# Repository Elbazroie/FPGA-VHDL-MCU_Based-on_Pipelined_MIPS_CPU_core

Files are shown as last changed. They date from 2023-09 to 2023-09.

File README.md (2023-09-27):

# FPGA-VHDL-MCU_Based-on_Pipelined_MIPS_CPU_core

This VHDL design includes Microcontroller UNIT based on MIPS PIPELINE CPU with one Delay slot architecture.

  The MCU design includes modules such as GPIO (LEDR,HEX0-5,SWITCH,KEYS), Basic Timer with OUTMOD capabilities and
	Interrupt controller Module with up to 5 PRIORITY interrupts (KEYS0-3, BASIC TIMER, NMI).

  The MIPS PIPLLINE design also includes HAZARD and forwarding unit that support stall and flush, to deal with RAW and control hazards (branch), and 
	added HARDWARE exclusively for INTERRUPT capabilities.
	the entire ISA supported included in the control.vhd file.

The design has been compiled and loaded to the FPGA Altera board ( Cyclone V ) for testing

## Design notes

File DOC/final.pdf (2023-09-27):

רועי אלבז 205868011
דור פטשניק 205556533

# Final Project

## MCU: based on Pipeline MIPS CPU - FPGA

בדו"ח זה נציג את הניתוח מימוש המיקרו בקר שתכננו המבוסס על מעבד מסוג MIPS pipelined

## Table of Contents

4 | ModelSim
8 | Quartus
18 | Signal Tap
מסקנות 20 |

אופן פעולה

בחלק זה נסביר את אופן הפעולה של הדיזיין שלנו MCU, ונכלול גם את התוספות והשינוים אותם

נדרשנו לבצע על מנת לתמוך במעבד מבוסס Pipeline MIPS.

דיאגרמת בלוקים כללית של הרכיב:

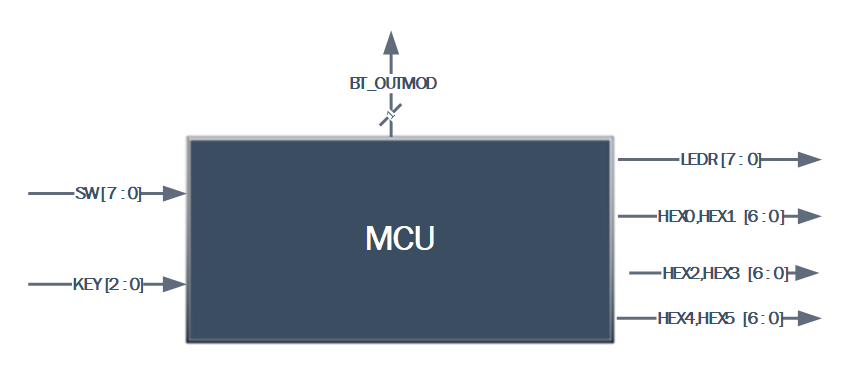
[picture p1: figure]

המיקרו-בקר שלנו מורכב מהרכיבים הבאים:

MIPS Pipeline | מבוסס | MIPS | מעבד | •
- מרכיבי GPIO בעלי יכולת קריאה וכתיבה )קריאה בלבד במקרה של רכיב INPUT )
- TIMER BASIC- בעל יכולת פסיקה בעת OVERFLOW ויציאת אות PWM בעל DUTY

CYCLE משתנה.

- CONTROLLER INTERRUPT- בעל יכולת פסיקה עם יכולת PRIORITY של פסיקה

ניתנות למיסוך ו-NMI. תומך בפסיקה מלחצנים, מTIMER ובביצוע RESET.

רכיבי GPIO:

מימשנו רכיבים אלה בצורה דומה להגדרת המשימה בתיאור הפרויקט. רכיבים אלה תלוים במודול

Select Chip אשר מעביר את קו הבקרה המתאים בהתאם לקידוד של קווי הכתובת הרלוונטים.

רגיסטרים בעלי יכולת כתיבה וקריאה )כגון IFG, BTCNT וכו'( מימשנו עם תוספת של בורר בכניסה

לרגיסטר שנפתח רק כאשר מתבצעת כתיבה או קריאה מהרכיב ועוצר את פעולתו, על מנת למנוע

מצב של DRIVEN MULTIPLE.

:INTERRUPT CONTROLLER

תוכנן כפי שהוגדר בהגדרת המשימה, עם תמיכה בפסיקות עם PRIORITY. מעלה קו בקרה INTR

בתחילת פסיקה ומקבל קו בקרה INTA בתחילת פעולת הפסיקה ומסיים את פעולתו כאשר קו זה

חוזר לערך 1 לוגי. כמו כן הוא מחובר באופן בלעדי לכפתור הRESET ומבצע אותו בתור פסיקה.

שאר המודולים במערכת מקבלים את הRESET ממודול זה על ידי קו בקרה סינכרוני NMI. כמו כן,

בעת RESET אנו מאפסים גם את מוצאי רכיבי הGPIO על ידי ערך הTYPE הנמצא על גבי

הDATABUS( ערכו הוא 0 בעת RESET)

:MIPS Pipeline

מעבד הPIPELINE ממעבדה 5 בעל מספר תוספות לתמיכה בפסיקות וGPIO:

.1 GPIO – עבודה אך ורק בשלב הDMEMORY.

a. תוספת של 2 TRISTATES בחיבור לdataBUS: במוצא הזכרון ובכניסת המידע

לזכרון. )עבור כתיבה וקריאה(

b. מניעת כתיבה לזכרון בעת פניה לרכיבי IO.
c. חיבור קו הכתובת בכניסה לזכרון אל הaddressBUS.

– INTERRUPT CONTROLLER .2

a. תוספת של MUX לקו הכתובת בכניסה לזכרון על מנת לכתוב את הTYPE בביצוע

.INTERRUPT

b. תוספת של קו EPC המחזיק את הכתובת הנכונה לקפיצה בשלב הEXECUTE.

נדרשנו להוסיף לוגיקה לתמיכה בjump conditional אשר משנה את הערך הבא

לקפיצה עקב שינוי הערך של הPC.

c. תמיכה בקפיצה לכתובת הפסיקה על ידי 2 ביטי עזר ISR המבצעים אמולציה של

פקודות LW וJAL.

d. העלאה והורדה של ביט הGIE בתחילת רוטינת פסיקה ובקבלת פקודת RETI.
e. הוספת STALL ליחידת ה HAZARD בעת ביצוע כתיבה לIFG לפני חזרה מרוטינת

פסיקה ) מונע מצב של כניסה לפסיקה נוספת למרות שהדגל המתאים היה אמור

לרדת(

ModelSim

נבצע את הניתוח בתוכנת ModelSim עבור מספר תוכניות שונות, ונבחן את התוצאות.

להלן קומפילציה של הדיזיין שלנו בתוכנת modelsim:

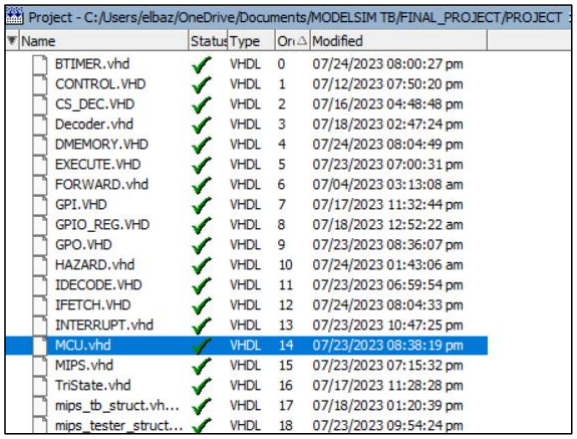
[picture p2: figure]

בשלב הסימולציה במודל סים נציג 5 טסטים לדוגמא: 2 עבור תקינות הGPIO, 2 עבור ה interrupt

controller ועוד בדיקה עבור אות הPWM של השעון.

:GPIO

קוד לדוגמא - 0Test:

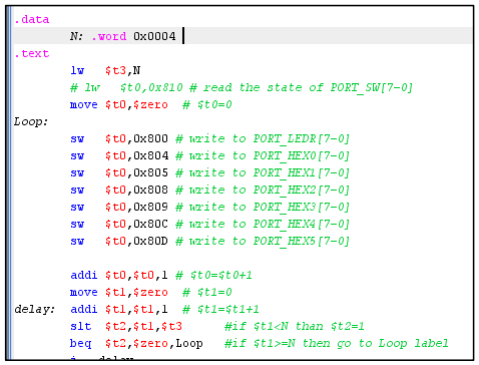
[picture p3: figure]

איור :2 קוד אסמבלי לדוגמא – 0test

איור :1 קומפילציה בMODELSIM עבור הMCU

בקוד זה אנו בודקים את תקינות רכיבי הGPO: HEX,LEDR. מבצעים מניה מעלה החל מהערך 0 וטוענים אותו ללדים ולנורות הHEX, עם דיליי של N.

בתמונה זו ניתן לראות את אופן הפעולה התקין – מניה מעלה של רכיבי הGPO שלנו. נציין כי ערכי

הHEX הן לאחר DECODE על מנת שיתאים לתצוגה על גבי הFPGA ולכן הם שונים מהערכים על

הלדים:

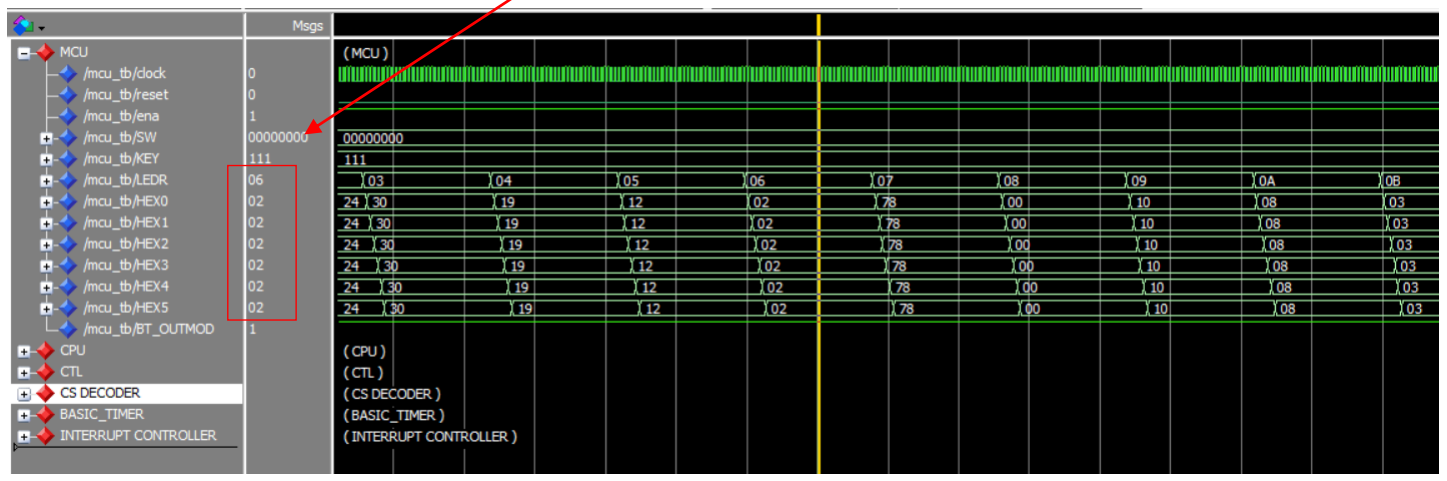
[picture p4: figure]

קוד לדוגמא – 2Test:

בקוד זה אנו בודקים את תקינות רכיבי הGPO: HEX,LEDR ואת רכיב הGPI SWITCHES. אנו מבצעים כפל ב2- או חלוקה ב2- של הערך ב0$t בצורה סריאלית, בהתאם לערך דיליי N. 1)=0(Sw גורר כפל ו1=(1)sw גורר חילוק.

בתמונה זו ניתן לראות את אופן הפעולה התקין – כאשר SW הוא 1 מתבצע כפל ב2- והצגה של

הערך על גבי רכיבי הGPO שלנו. לאחר מכן SW משתנה ל2 ואנו עוברים לביצוע חילוק ב.2-

איור :3 ביצוע מניה מעלה של ערכי HEX ו LEDR

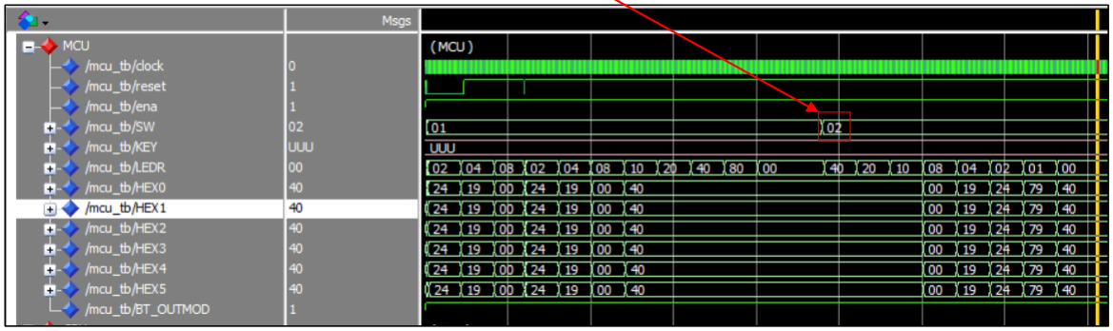
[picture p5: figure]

איור :4 ביצוע כפל\חילוק ב 2 והצגה על גבי הLEDR וHEX

:INTERRUPT I/O

קוד לדוגמא – 2Test:

בקוד זה אנו בודקים את תקינותו של בקר הפסיקות אל מול הלחצנים 1-3KEY והTIMER BASIC. בנוסף עבודה עם הLEDR וHEX. בהתחלה מבצעים אתחול של השעון ומאפשרים פסיקות.

בעת פסיקה אמורות להתבצע הפעולות הבאות:

1-3KEY – כתיבה של ערך הלדים 4-5HEX / 2-3HEX / 0-1HEX בהתאמה.

TIMER BASIC – מנייה מעלה, החל מערך הSW וכתיבה של הערך ללדים.

בתמונה זו ניתן לראות את המניה של הלדים עקב פסיקות של השעון ואת עדכון הערכים של הלדים בHEX המתאימים, בהתאם ללחצן שנבחר. בחלק זה ניתן גם להבחין בPRIORITY- 0KEY ו2KEY נלחצו בו זמנית וביצענו פסיקה ל 0- שהוא בעל העדיפות הגבוהה מביניהם.

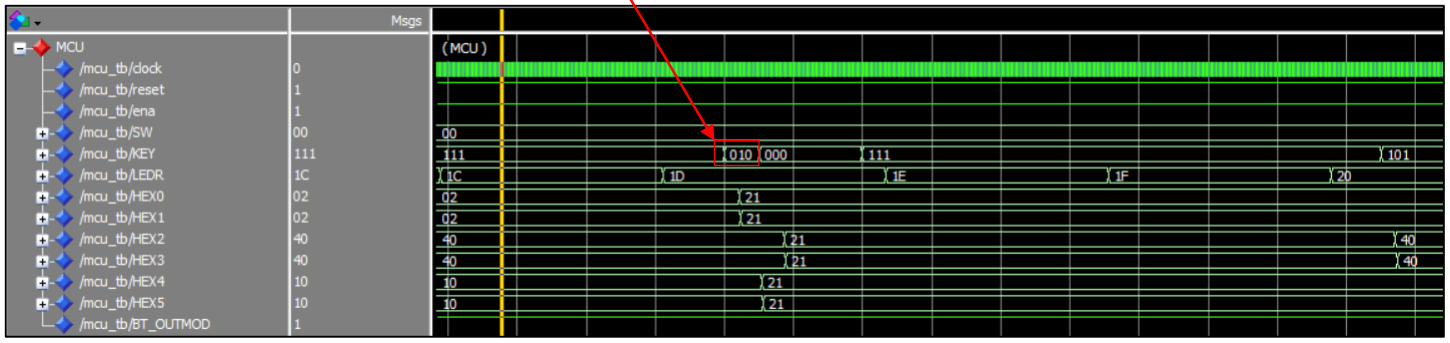
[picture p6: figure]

איור :5 ביצוע פסיקות לחצנים וטיימר והצגה על גבי הLEDR וHEX

בתמונה זו ניתן לראות דוגמא לפעולת הפסיקה במודול הcontroller intrerrupt. ברגע העליה של INTR יורד ביט INTA ועולה חזרה בסיום הפעולה. כמו כן, בסיומה של הפעולה אנו כותבים לBUS את ערך הtype ומקבלים את ערך כתובת רוטינת הפסיקה מהזכרון. ניתן גם לראות ירידה של GIE.

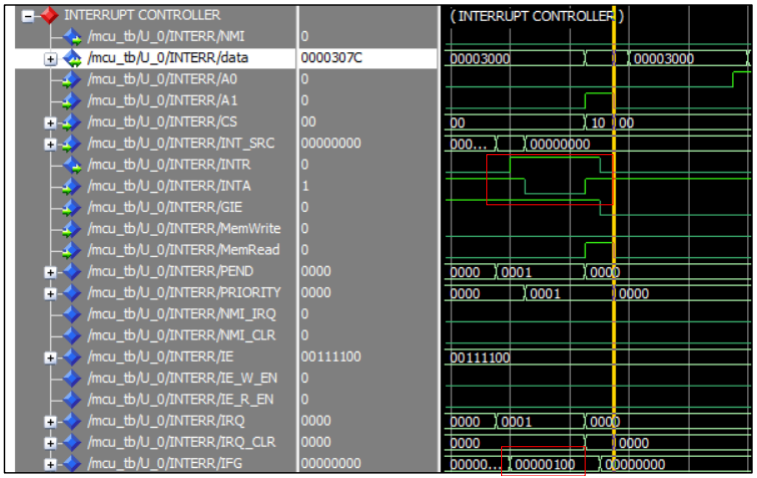
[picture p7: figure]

קוד לדוגמא – 3Test:

בקוד זה אנו בודקים את תקינותו של בקר הפסיקות אל מול הלחצנים 1-3KEY והTIMER BASIC. בנוסף עבודה עם הLEDR וHEX. בהתחלה מבצעים אתחול של השעון ומאפשרים פסיקות.

בעת לחיצה על הלחצנים, נקנפג מחדש את רגיסטר הבקרה של הטיימר ובכך נשנה את מהירות המנייה של הלדים. הtimer basic מונה ערך ללדים בכל פסיקה.

כאן ניתן לראות את הכניסה לפסיקת אחד הלחצנים ושינוי ערך רגיסטר הבקרה של הטיימר. בעקבות כך שינינו את תדר השעון ואת קצב המניה של הלדים.

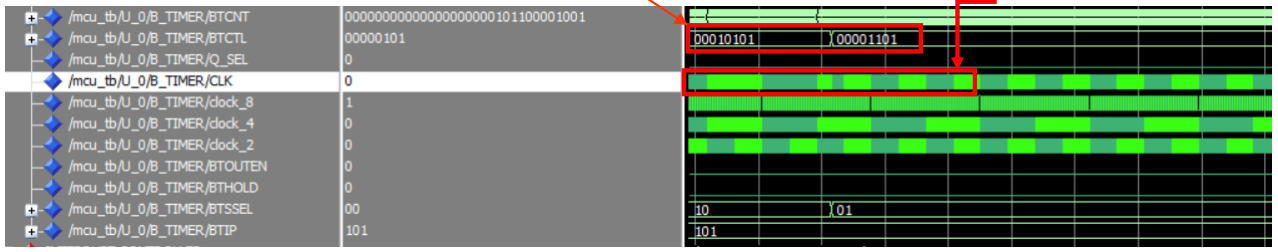
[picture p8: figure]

איור :7 שינוי פעולת הטיימר עקב פסיקת לחצן

איור :6 ביצוע רוטינת פסיקה

קוד לדוגמא – OUTMOD:

בקוד זה אנו בודקים את תקינותו של מוד שידור אות הPWM שלנו.

להלן דוגמא לשידור אות PWM עם DUTYCYCLE של כ .88.5% אות הPWM נקבע על ידי ערכי הרגיסטרים 1BTCCR0,BTCCR. מכיוון שאנו עובדים במוד של set/toggle, הDUTYCYCLE נקבע לפי
2048 = ¹¹ ( חלקי ההפרש בין הרגיסטרים 1BTCCR0,BTCCR | ערך המניה של הטי ימר )במקרה שלנו 2
7 | )במקרה שלנו F = F2 − F3( ולכן נקבל ש ב
8

מהמחזור אנו ב1 לוגי , כפי שקיבלנו.

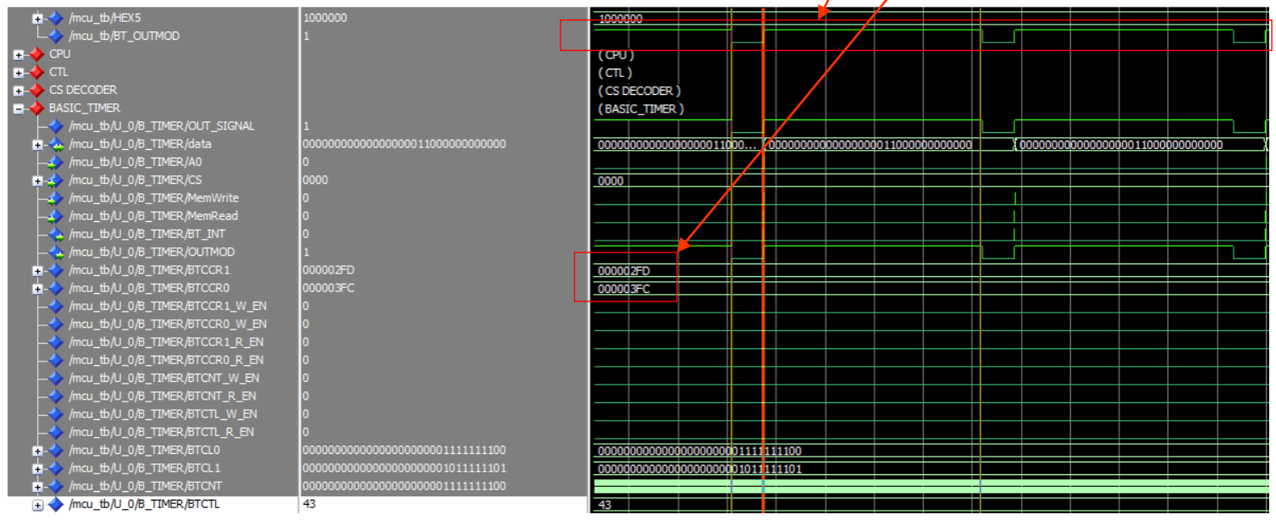
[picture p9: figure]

Quartus

### MCU

.1 ראשית, קומפילציה של הMCU שלנו:

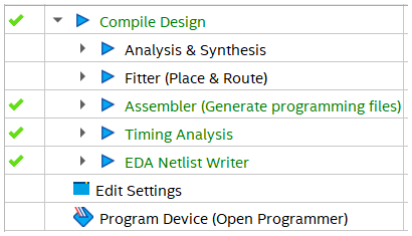
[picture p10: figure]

איור :9 קומפילציה של Quartus ללא הקצאות פינים

איור :8 אות PWM על ידי הטיימר

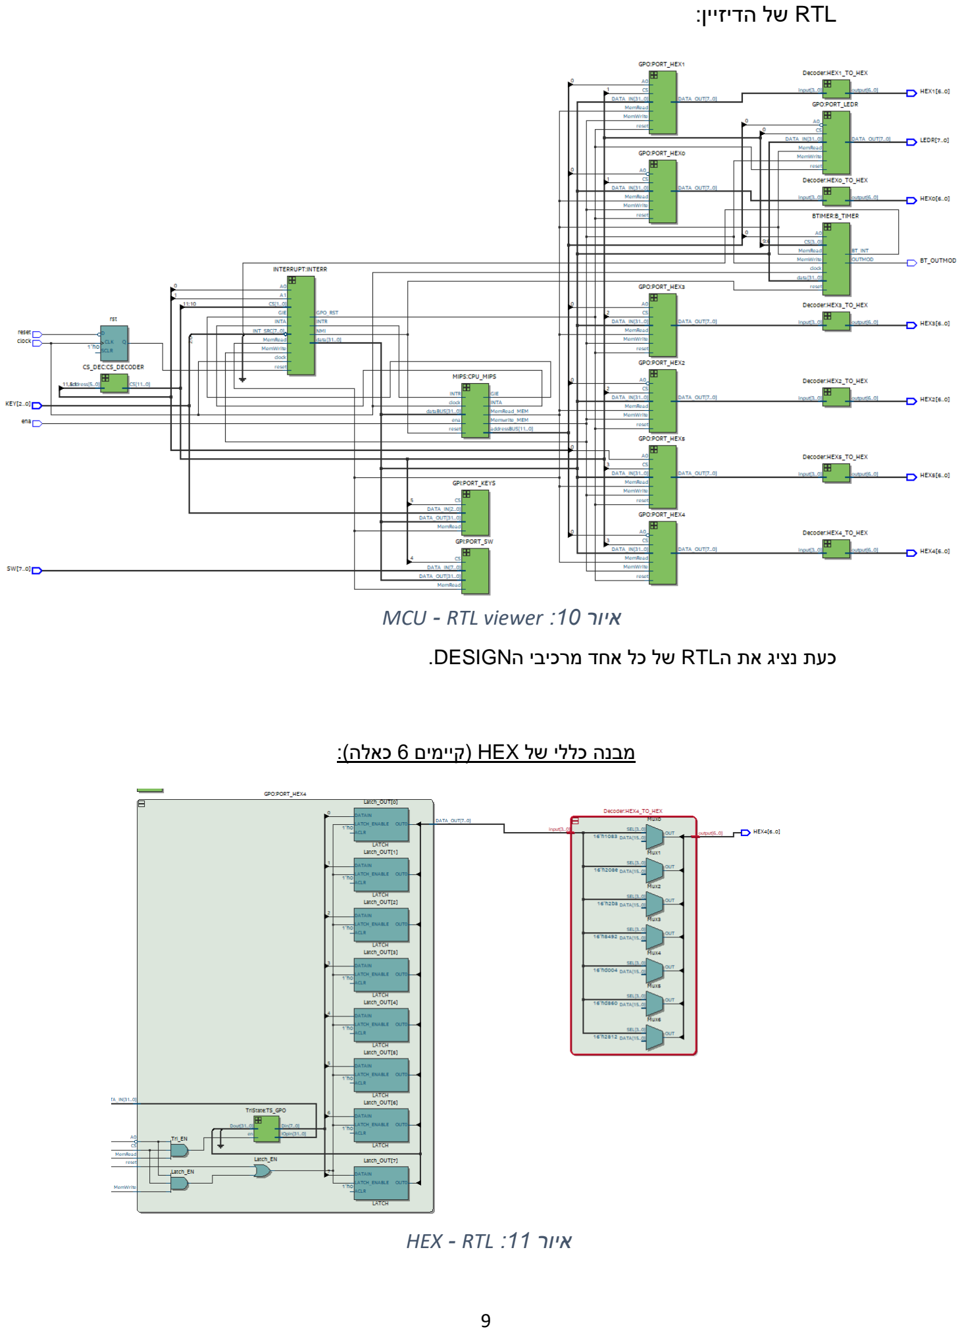
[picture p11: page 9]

RTL של הדיזיין:

כעת נציג את הRTL של כל אחד מרכיבי הDESIGN.

מבנה כללי של HEX( קיימים 6 כאלה(:

MCU - RTL viewer :10 | איור
HEX - RTL :11 | איור

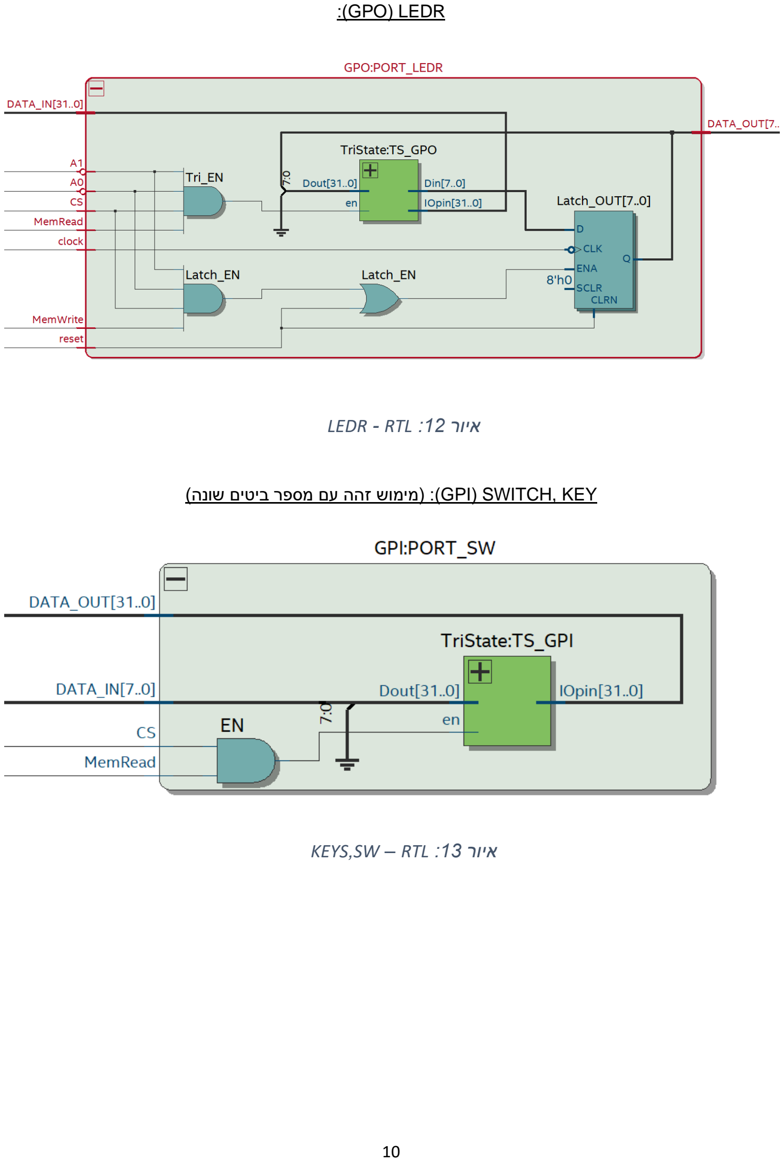
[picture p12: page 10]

:)GPO( LEDR

KEY ,SWITCH ( GPI):( מימוש זהה עם מספר ביטים שונה(

LEDR - RTL :12 | איור
KEYS,SW – RTL :13 | איור

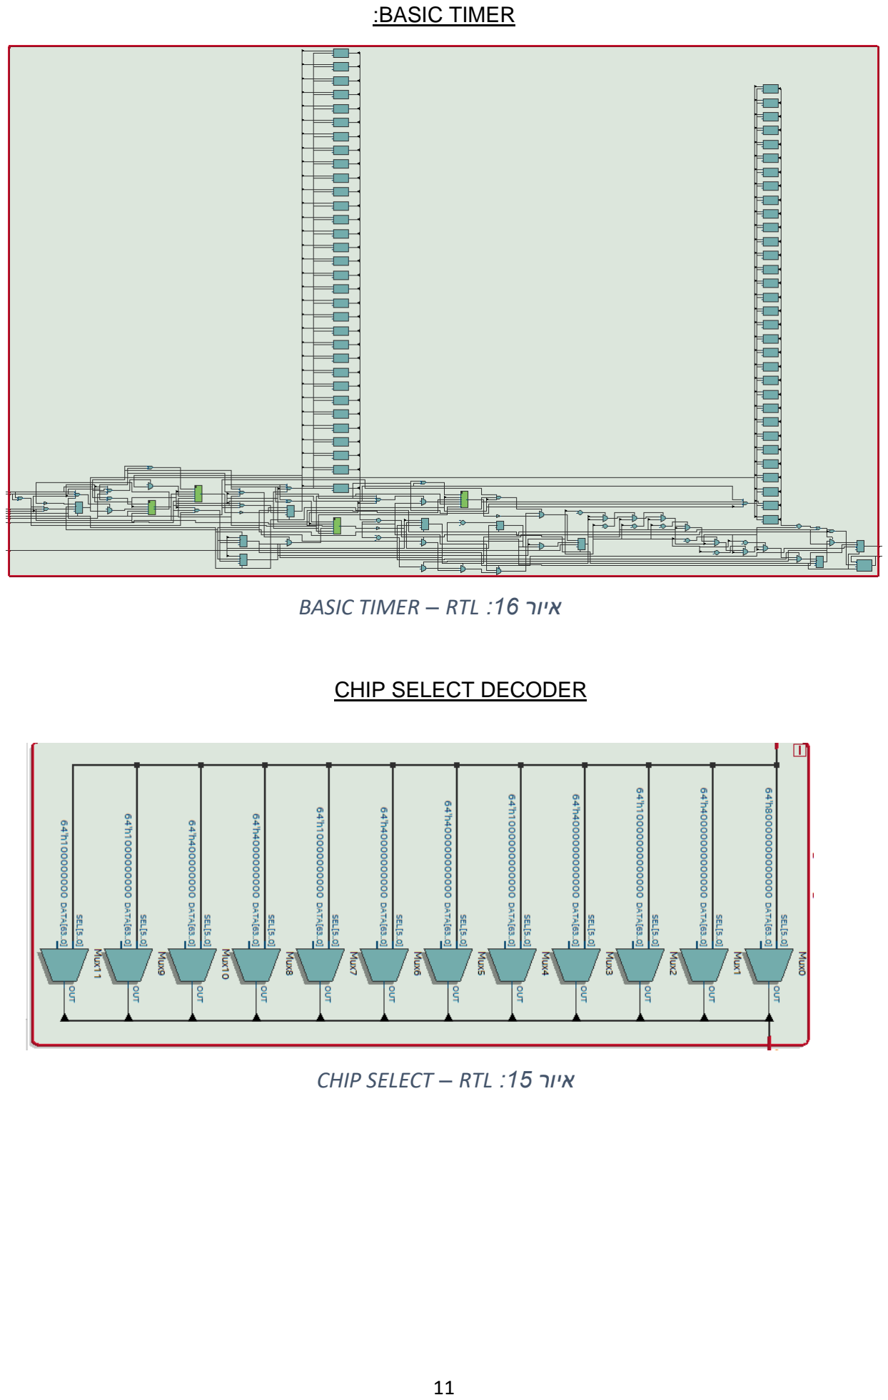
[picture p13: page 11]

:BASIC TIMER

BASIC TIMER CHIP SELECT – RTLDECODER :14 | איור
CHIP SELECT – RTL :15 | איור
BASIC TIMER – RTL :16 | איור

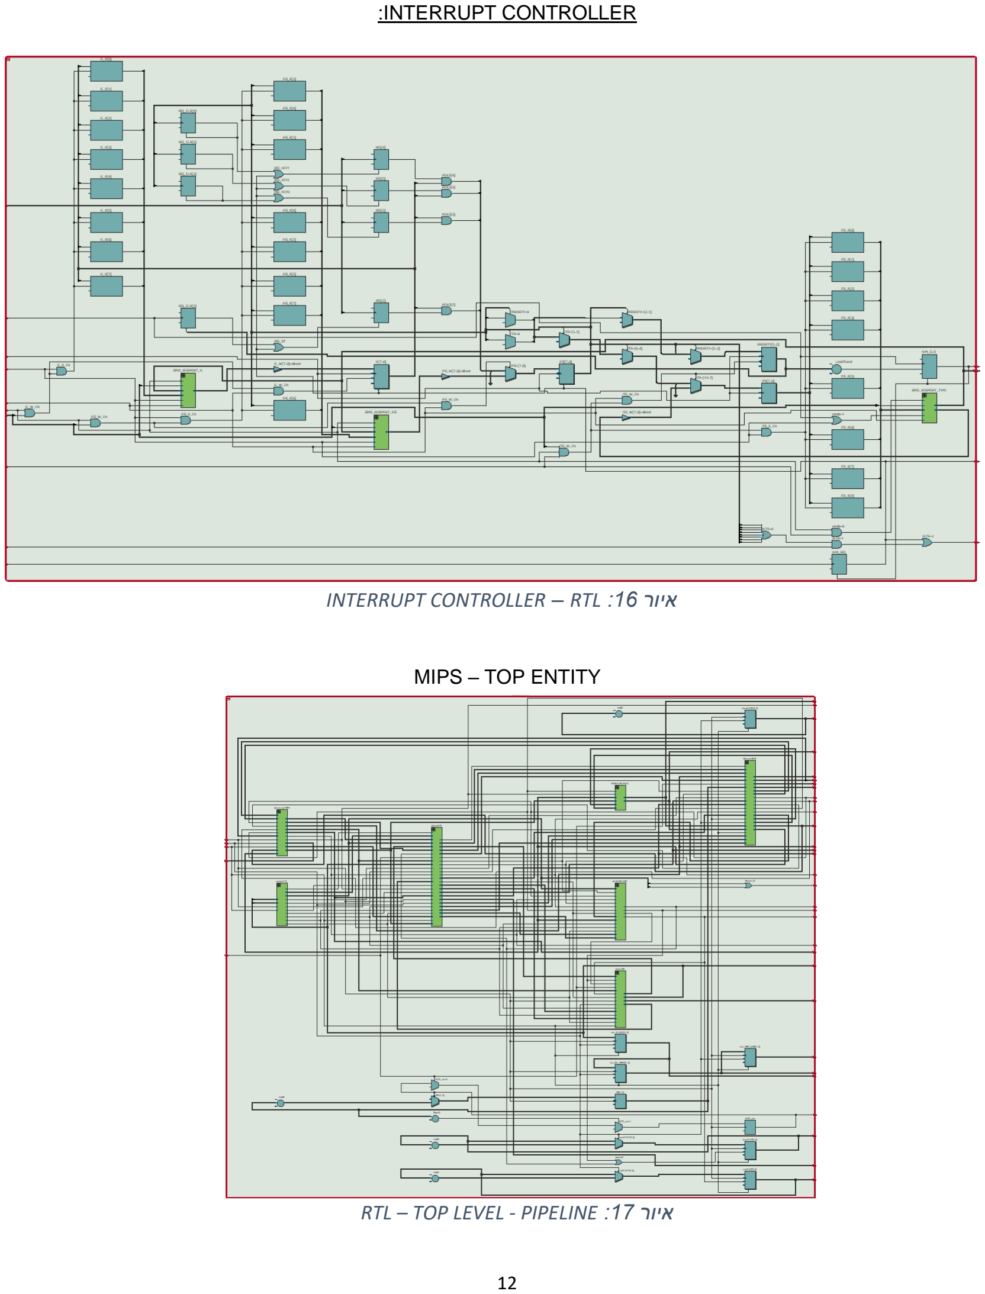
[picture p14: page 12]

:INTERRUPT CONTROLLER

MIPS – TOP ENTITY

INTERRUPT CONTROLLER – RTL :16 | איור
RTL – TOP LEVEL - PIPELINE :17 | איור

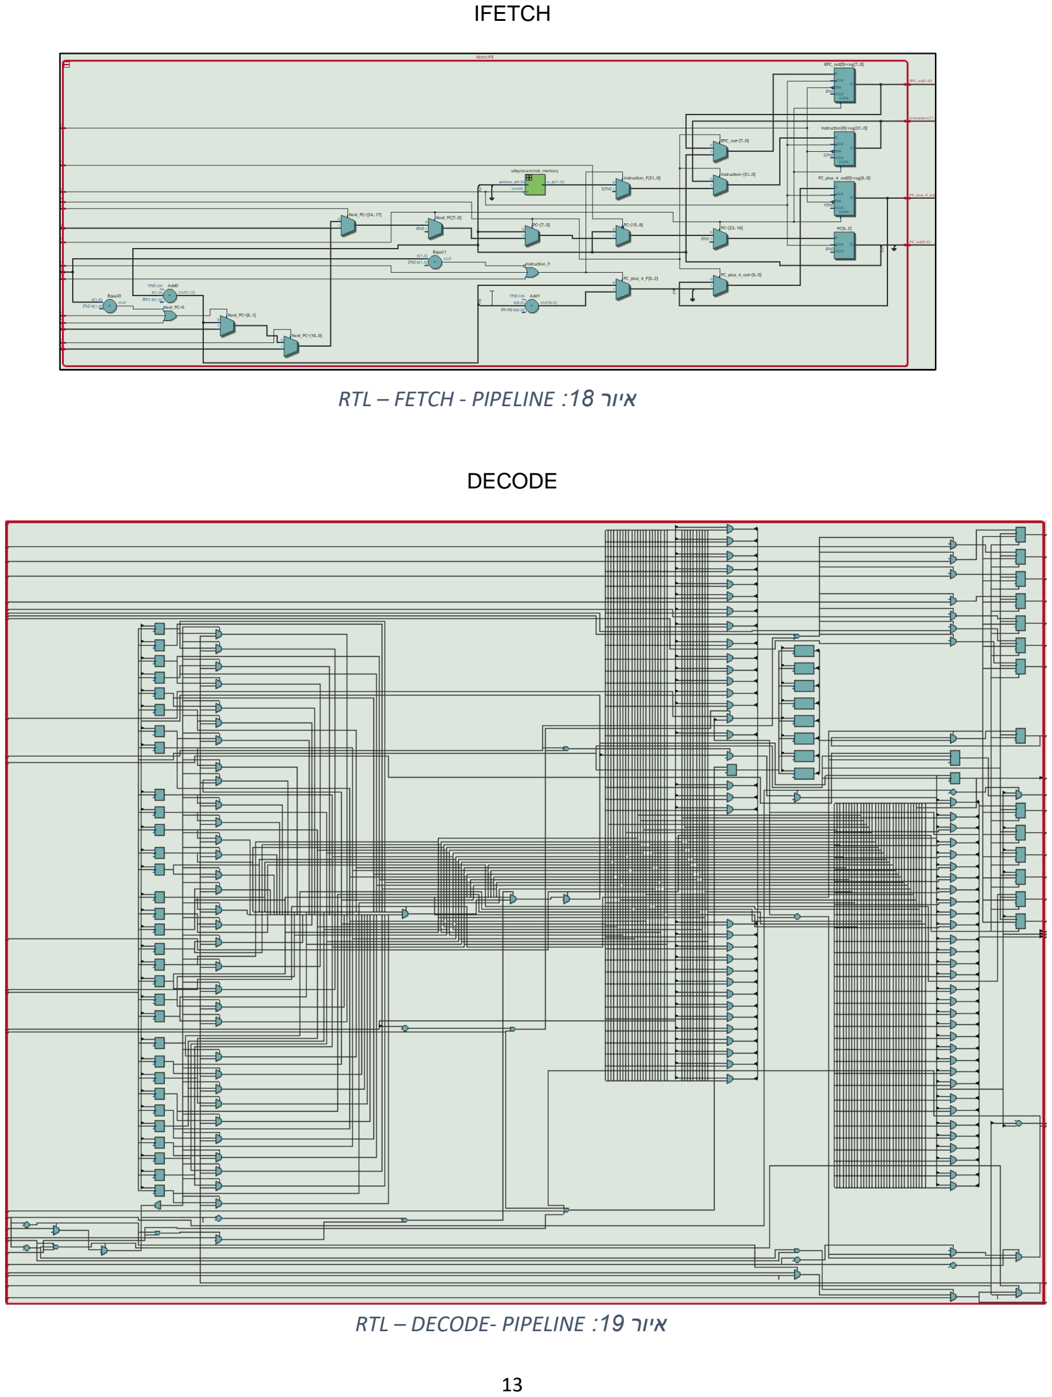
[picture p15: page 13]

IFETCH

DECODE

RTL – FETCH - PIPELINE :18 | איור
RTL – DECODE- PIPELINE :19 | איור

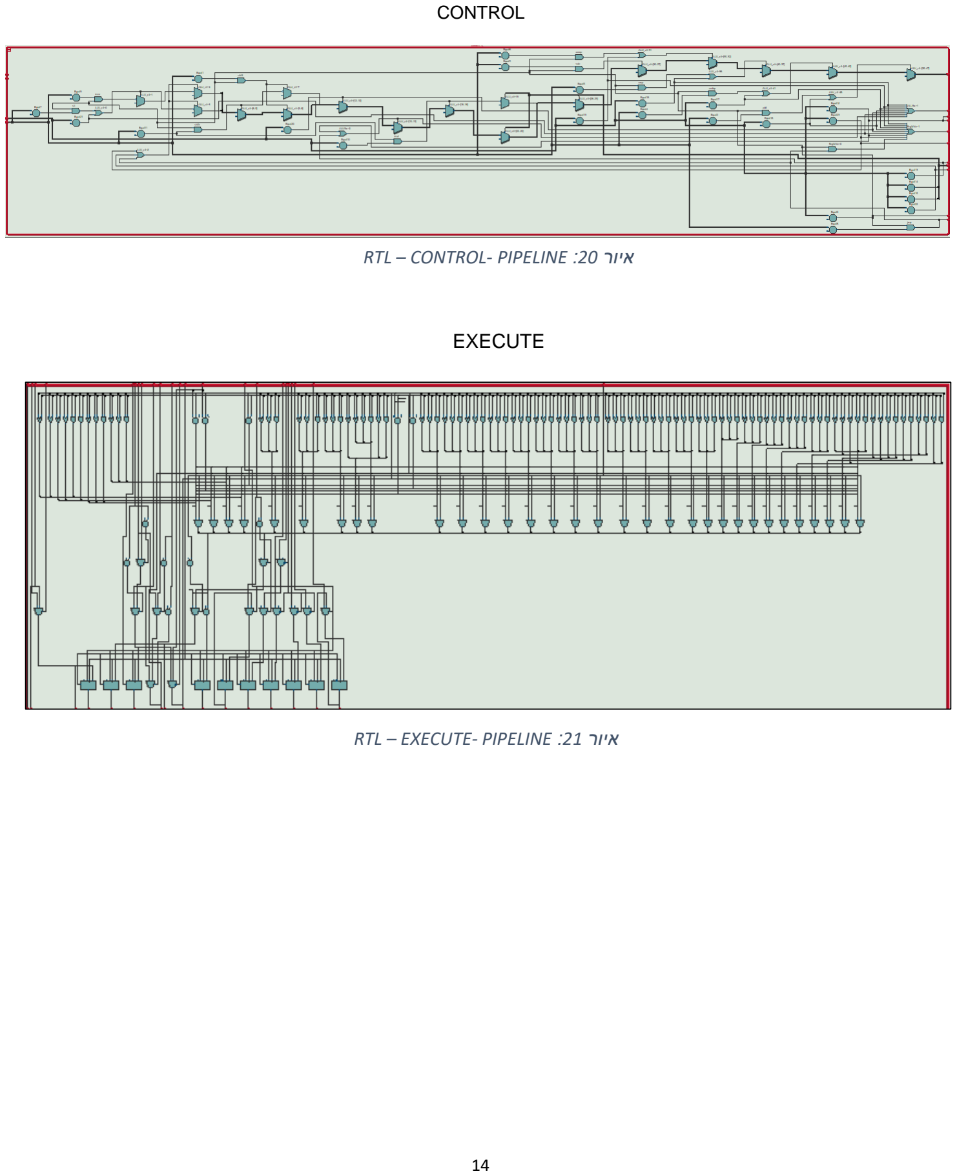
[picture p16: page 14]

CONTROL

RTL – CONTROL- PIPELINE :20 | איור
RTL – EXECUTE- PIPELINE :21 | איור

EXECUTE

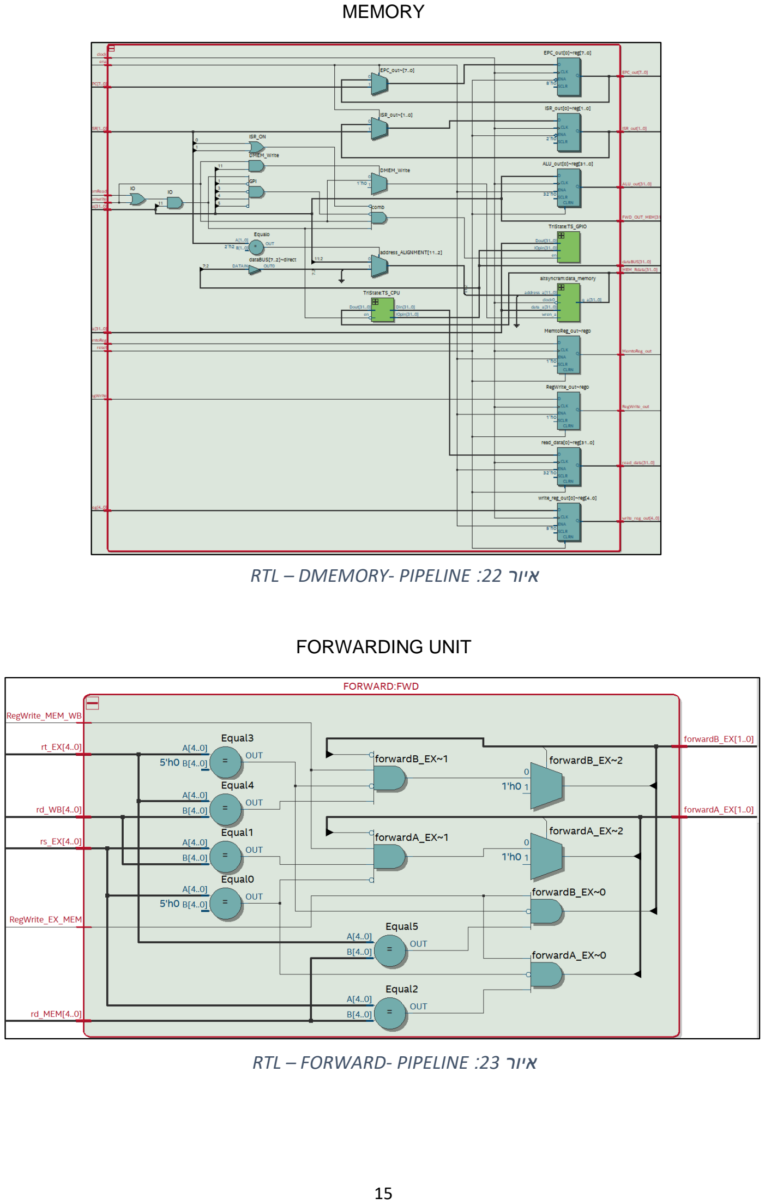
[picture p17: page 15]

MEMORY

FORWARDING UNIT

RTL – DMEMORY- PIPELINE :22 | איור
RTL – FORWARD- PIPELINE :23 | איור

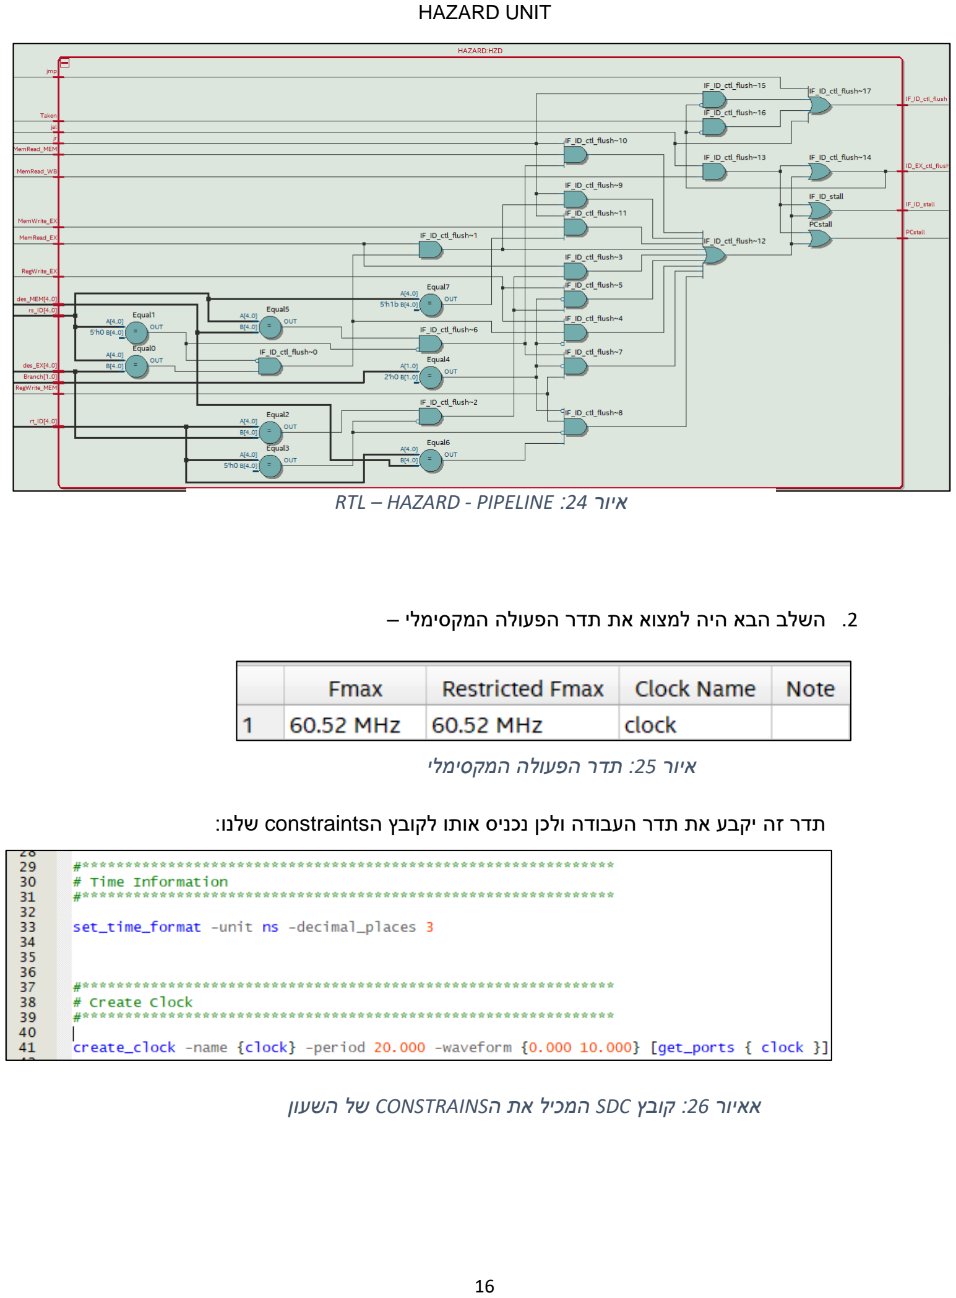
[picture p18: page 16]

HAZARD UNIT

.2 השלב הבא היה למצוא את תדר הפעולה המקסימלי –

איור :25 תדר הפעולה המקסימלי

תדר זה יקבע את תדר העבודה ולכן נכניס אותו לקובץ הconstraints שלנו:

אאיור :26 קובץ SDC המכיל את הCONSTRAINS של השעון

RTL – HAZARD - PIPELINE :24 איור

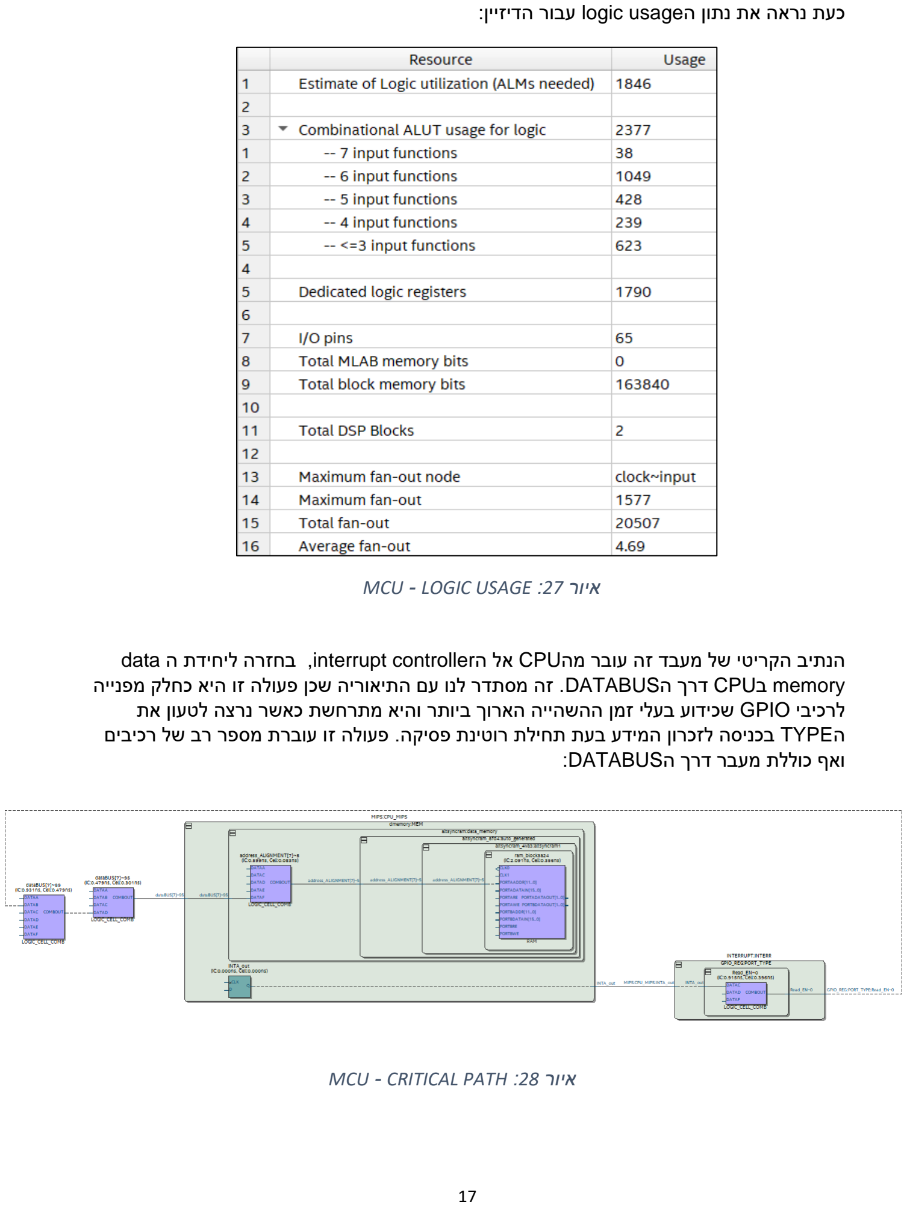
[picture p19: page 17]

כעת נראה את נתון הusage logic עבור הדיזיין:

הנתיב הקריטי של מעבד זה עובר מהCPU אל הcontroller interrupt, בחזרה ליחידת ה data memory בCPU דרך הDATABUS. זה מסתדר לנו עם התיאוריה שכן פעולה זו היא כחלק מפנייה לרכיבי GPIO שכידוע בעלי זמן ההשהייה הארוך ביותר והיא מתרחשת כאשר נרצה לטעון את הTYPE בכניסה לזכרון המידע בעת תחילת רוטינת פסיקה. פעולה זו עוברת מספר רב של רכיבים ואף כוללת מעבר דרך הDATABUS:

MCU - LOGIC USAGE :27 | איור
MCU - CRITICAL PATH :28 | איור

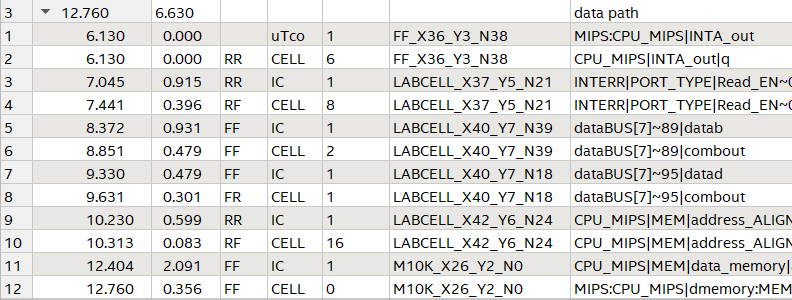
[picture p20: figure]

Signal Tap

נרצה לבצע ווריפיקציה של החומרה שיצרנו בעזרת תוכנת ה aT angiS של utrauQ ,

נרצה להציג בזמן אמת את ערכי סיגנלים נבחרים עבור וריפיקציה מיטבית של הדיזיין שלנו. לכידת

ערכים בtap signal תתבצע בעת לחיצה על אחד הלחצנים או בעת הורדת הENA. בfpga נוכל

לראות בצורה דינמית את השפעת הפסיקות על המערכת.

טבלת הסיגנלים שנרצה לדגום:

איור :29 פירוט הזמנים של הcritical path - MCU

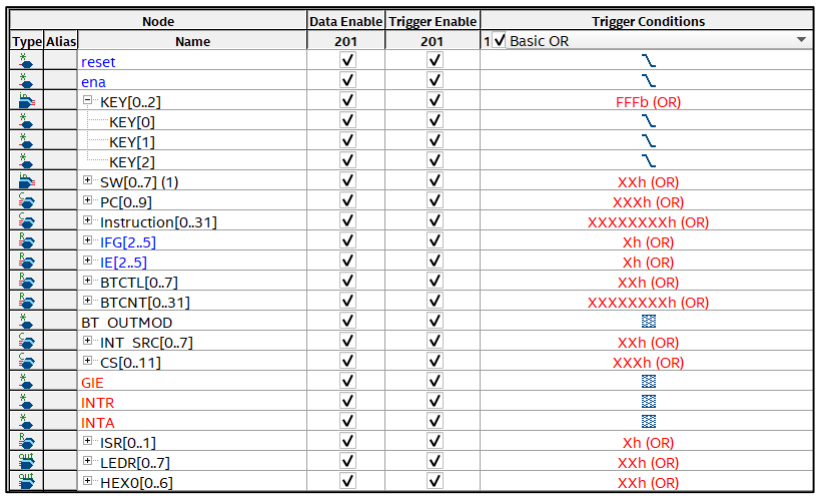
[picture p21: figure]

signal tap signal triggers - MCU :30 איור

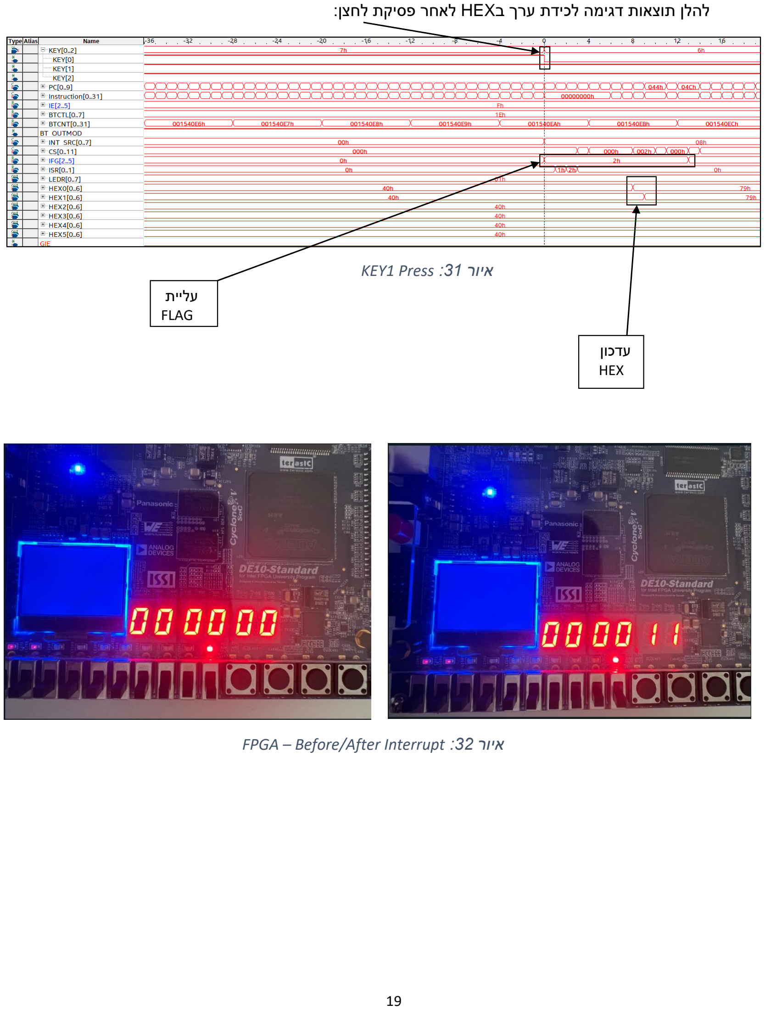
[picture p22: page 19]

להלן תוצאות דגימה לכידת ערך בHEX לאחר פסיקת לחצן:

KEY1 Press :31 איור

עליית
FLAG

עדכון
HEX

FPGA – Before/After Interrupt :32 איור

מסקנות

- עבודה לפי סדר פעולות- תכנון של MCU המבוסס על מעבד הsinglecycle ולאחר מכן

מעבר לפייפלין. תהליך זה עזר מאוד להבנת אופן הפעולה של המודולים החדשים שנוספו.

- נדרשה הכנה תיאורטית מעמיקה לפני שלב התכנון, בעיקר בנושא של טיפול בפסיקות

והממשק בין הCPU לבקר פסיקות. זהו שלב שלא ניתן לדלג עליו מכיוון שהוא מקל מאוד על

תהליך התכנון ומאפשר התמודדות פשוטה יותר עם תקלות.

- שינוי אופן עבודת הRESET ומעבר לפסיקת NMI היה חלק חשוב בשלב התכנון שעזר לנו

להתמודד עם הצורך באיפוס ערכי הGPO בצורה נכונה.

- נקודה חשובה נוספת שלמדנו במהלך התכנון היא שהפונקציות edge falling/rising

מיועדות לקווי שעון בלבד ושימוש בהם עבור סיגנלים בתוכנית יוצר בעיה בתפקוד המערכת.

התגברנו על הצורך בהם על ידי דגימה של עליה וירידת שעון באמצעות סיגנלי עזר

המוקדשים לכך.

- הQUARTUS עובד לפי קריאה של בתים מהזכרון, בעוד ModelSim עובד לפי מילים.

הגדרנו זאת באמצעות ביצוע GENERATE IF עבור כל אחת מסביבות העבודה. זוהי נקודה

קריטית אשר בזכותה קיבלנו ערכי דגימה זהים בשני המקרים.

- הצלחנו להתגבר על הבעיה בISCME שהייתה קיימת במעבדות קודמות הקשורה לקריאה

וכתיבה אל הזכרון בQUARTUS בזמן אמת. יכולת זו עזרה לנו משמעותית בוריפיקציה של

המערכת מכיוון שזה חסך לנו את הצורך לבצע קומפלציה כל פעם שרצינו להריץ תוכנית

חדשה.

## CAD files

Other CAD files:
QUARTUS/stp.stp

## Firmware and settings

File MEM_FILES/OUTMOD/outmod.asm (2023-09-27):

#--------------------------------------------------------------
#		    MEMORY Mapped I/O
#--------------------------------------------------------------
#define PORT_LEDR[7-0] 0x800 - LSB byte (Output Mode)
#------------------- PORT_HEX0_HEX1 ---------------------------
#define PORT_HEX0[7-0] 0x804 - LSB byte (Output Mode)
#define PORT_HEX1[7-0] 0x805 - LSB byte (Output Mode)
#------------------- PORT_HEX2_HEX3 ---------------------------
#define PORT_HEX2[7-0] 0x808 - LSB byte (Output Mode)
#define PORT_HEX3[7-0] 0x809 - LSB byte (Output Mode)
#------------------- PORT_HEX4_HEX5 ---------------------------
#define PORT_HEX4[7-0] 0x80C - LSB byte (Output Mode)
#define PORT_HEX5[7-0] 0x80D - LSB byte (Output Mode)
#--------------------------------------------------------------
#define PORT_SW[7-0]   0x810 - LSB byte (Input Mode)
#--------------------------------------------------------------
#define PORT_KEY[3-1]  0x814 - LSB nibble (3 push-buttons - Input Mode)
#--------------------------------------------------------------
#define UCTL           0x818 - Byte 
#define RXBF           0x819 - Byte 
#define TXBF           0x81A - Byte
#--------------------------------------------------------------
#define BTCTL          0x81C - LSB byte 
#define BTCNT          0x820 - Word 
#define BTCCR0         0x824 - Word 
#define BTCCR1         0x828 - Word 
#--------------------------------------------------------------
#define IE             0x82C - LSB byte 
#define IFG            0x82D - LSB byte
#define TYPE           0x82E - LSB byte
#---------------------- Data Segment --------------------------
.data 
	IV: 	.word main            # Start of Interrupt Vector Table
		.word UartRX_ISR
		.word UartRX_ISR
		.word UartTX_ISR
	        .word BT_ISR
		.word KEY1_ISR
		.word KEY2_ISR
		.word KEY3_ISR

	N:	.word 0xFFFF
	
#---------------------- Code Segment --------------------------	
.text
main:	addi $sp,$zero,0x800 # $sp=0x800
	addi $t0,$zero,0x63  
	sw   $t0,0x81C       # BTCTL=0x3B(BTIP=3, BTSSEL=3, BTHOLD=1)
	addi $t1,$zero,0x03FC  	
	addi $t2,$zero,0x02FD 
	sw   $t1,0x824        # BTCCCR0=0	
	sw   $t2,0x828        # BTCCCR1=0			
	sw   $0,0x820        # BTCNT=0
	sw   $0,0x82C        # IE=0
	sw   $0,0x82D        # IFG=0
	
	addi $t0,$zero,0x43  
	sw   $t0,0x81C       # BTIP=3, BTSSEL=3, BTHOLD=0
	addi $t0,$zero,0x3C 
	sw   $t0,0x82C       # IE=0x3C
	ori  $k0,$k0,0x01    # EINT, $k0[0]=1 uses as GIE
	
	lw   $t0,0x810       # read the state of PORT_SW[7-0]
L:	j    L		    # infinite loop
				
KEY1_ISR:
	sw   $t0,0x804 # write to PORT_HEX0[7-0]
	sw   $t0,0x805 # write to PORT_HEX1[7-0]
	
	lw   $t1,0x82D # read IFG
	andi $t1,$t1,0xFFF7 
	sw   $t1,0x82D # clr KEY1IFG
	jr   $k1       # reti
	
KEY2_ISR:
	sw   $t0,0x808 # write to PORT_HEX2[7-0]
	sw   $t0,0x809 # write to PORT_HEX3[7-0]
	
	lw   $t1,0x82D  # read IFG
	andi $t1,$t1,0xFFEF 
	sw   $t1,0x82D  # clr KEY2IFG
	jr   $k1        # reti

KEY3_ISR:
	sw   $t0,0x80C # write to PORT_HEX4[7-0]
	sw   $t0,0x80D # write to PORT_HEX5[7-0]
	
	lw   $t1,0x82D  # read IFG
	andi $t1,$t1,0xFFDF 
	sw   $t1,0x82D  # clr KEY3IFG
	jr   $k1        # reti
		
BT_ISR:	addi $t0,$t0,1  # $t1=$t1+1
	sw   $t0,0x800 # write to PORT_LEDR[7-0]
        jr   $k1        # reti
         
UartRX_ISR:
UartTX_ISR:
